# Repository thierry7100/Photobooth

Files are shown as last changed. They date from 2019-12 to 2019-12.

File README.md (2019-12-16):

## Software
* PhotoBooth_3Img_mariage.py : PhotoBooth main daemon. handle taking picture and upload to google drive
* listen-for-shutdown.py : management software :
  * starting/stopping camera_btn.py (short press)
  * powering off RPi (long press)
* *.service : systemctl services definition

## Install

Based on [Raspbian](https://www.raspberrypi.org/downloads/raspbian/)

Install shutdown service

    sudo cp listen-for-shutdown.service /etc/systemd/system/
    sudo systemctl daemon-reload
    sudo systemctl enable listen-for-shutdown.service
    sudo systemctl start listen-for-shutdown.service

Install Photobooth service

    sudo cp photobooth.service /etc/systemd/system/
    sudo systemctl daemon-reload
    sudo systemctl enable photobooth.service
    sudo systemctl start photobooth.service

Install needed python modules

    pip install --upgrade google-api-python-client

get api ID clients OAuth 2.0 client_id.json and put in current directory. See https://console.developers.google.com/apis/credentials

## Customization
There's some images displayed by the PhotoBooth service. They are overlayed on top of the live image.
The documentation explains how to change these images

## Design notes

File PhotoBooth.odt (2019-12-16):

Un photomaton (Photo-Booth) pour animer des événements

Ce type d’équipement permet de s’amuser lors d’événements comme des mariages, fêtes diverses… Il permet de réaliser des photos où les personnes « se lâchent » ou pas d’ailleurs !

J’ai réalisé ce type d’équipement pour le mariage de ma seconde fille. Lors du mariage de la première, elle avait loué ce type d’équipement, cela est revenu à 300€ pour le week-end ! Je me suis dit que je devais pouvoir faire sinon mieux, au moins différent et pour un budget beaucoup plus modique, tout en restant disponible pour d’autres occasions.

Les photos sont loin d’avoir la qualité d’un appareil numérique récent, mais cela reste tout à fait viable pour ce type d’usage.

J’ai choisi délibérément un style rétro, mais ne vous y fiez pas, cet appareil permet d’imprimer 3 photos regroupées en direct, et permet également d’envoyer en direct les photos prises sur Google Drive pour les partager ensuite facilement. Ceci nécessite bien sûr une connectivité réseau, Wifi ou Ethernet.

Le logiciel permet relativement facilement de configurer le nombre de photos à imprimer (cela peut être 0), le compte Google Drive à utiliser, l’image de fond choisie...

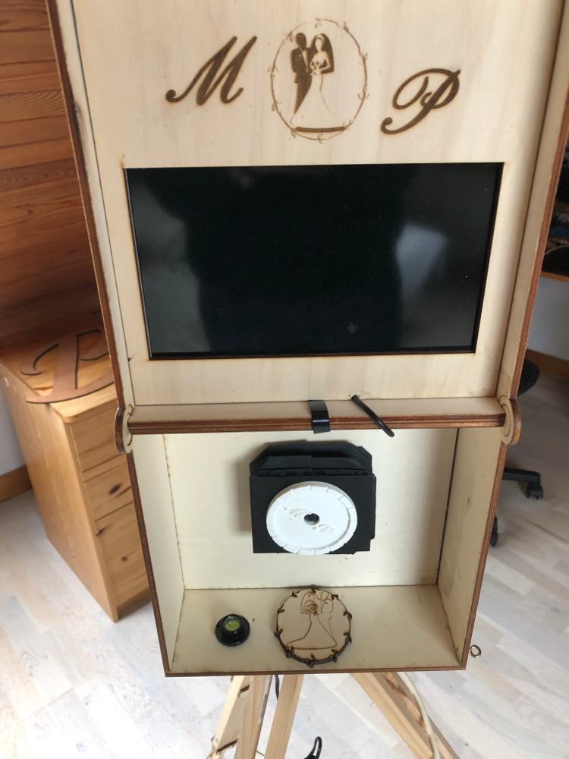
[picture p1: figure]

# Matériel

1. Du bois… J’ai utilisé du contreplaqué peuplier (très clair) pour le boîtier, du tasseau en pin pour les pieds, un peu de MDF pour le support d’objectif.
2. Un Raspberry PI3 et sa caméra v2.
3. Un petit niveau (acheté sur un site de camping car), non obligatoire, mais permet de mettre l’appareil à peu près à l’horizontale.
4. Du papier noir épais pour le soufflet (acheté à Bureau Vallée).
5. Un écran 9 pouces avec entrée HDMI, acheté chez Ali Express. La résolution est de 800 par 480 pixels. L’écran n’est pas de très bonne qualité, mais le prix (27€) est au rendez-vous. https://fr.aliexpress.com/item/32707130877.html?spm=a2g0s.9042311.0.0.27426c37Hc6uQq
6. Un câble HDMI réalisé en circuit imprimé souple pour relier l’écran et permettre de mettre l’écran dans le couvercle du boîtier. https://www.amazon.fr/dp/B01EWSKVDQ/ref=pe_3044141_185740131_TE_item
7. Une alimentation 5V USB, pour l’écran et le Raspberry. J’ai choisi e prendre deux alimentations différentes pour ne pas avoir de problème de consommation.
8. Un petit amplificateur BF avec un haut parleur pour la partie son. https://www.gotronic.fr/art-kit-2165b-653.htm.
9. Des boutons, issus d’un site de boutons de gamers… http://www.joystick-arcade.com/fr/
10. Quelques vis de tailles diverses...

# Boîtier

J’ai utilisé les boîtes générées par le site de Florian Festi pour cette occasion. Voir www.festi.info/boxes.py

Parmi toutes les formes de boîtes disponibles, j’ai utilisé une avec des charnières en bois intégrées qui permettent de replier l’écran une fois rangé. L’écran est ainsi au dessus de l’appareil, et permet une prise de vue correcte, avec un effet « faux jeton » à mon avis moins marqué que s’il était déporté sur le côté. Pour les meilleures prises de vue possibles, il faut néanmoins regarder l’objectif et pas l’écran !

La décoration est très ‘kitch’, j’en conviens mais si vous voulez en changer ne vous gênez pas !

Aujourd’hui, j’utiliserai plutôt le plugin inkscape que j’ai réalisé (on n’est jamais mieux servi que par soi-même pour se faire un peu de pub…), voir https://wiki.fablab-lannion.org/index.php?title=Generateur_de_boites. Je recommande ce plugin, car le dessin généré par le site de Florian Festi présente quelques défauts (mineurs) et surtout le fichier SVG généré incorpore de nombreux arrondis qui passent très mal avec RDWorks et notre découpeuse Laser. Les arrondis sont transformés encercles complets, et génèrent beaucoup de mouvements parasites pouvant conduire à des décalages.

## Support écran

Le support d’écran est coincé dans le couvercle du boîtier. Il est constitué de 3 plaques permettant de fixer l’écran. La première plaque (gravée) est réalisée en CP5mm est la plaque externe. LA seconde plaque (MDF 3mm) permet de caler l’écran, la troisième plaque (visée sur la seconde empêche l’écran de bouger). Prendre du bois de 3mm d’épaisseur, c’est celle de l’écran. La carte contrôleur d’écran est vissée sur la 3ème plaque. Cet assemblage est ensuite inséré dans le couvercle, la profondeur est dans mon cas réglée par des tasseaux collés dans le couvercle. J’ai collé l’ensemble, ce n’est pas démontable, mais cela ne me paraissait pas nécessaire.

Voir fichier BoiteEcran.XXX dans le répertoire Decoupe.

# Objectif photo

J’utilise la caméra du raspberry (v2) directement, mais il faut l’habiller.

## Le soufflet

Tout bon appareil rétro qui se respecte doit avoir son soufflet ! Ici bien sûr il ne sert à rien. J’ai réalisé le mien en papier épais, genre papier canson en plus épais (noir). Je me suis basé sur cet article : http://www.galerie-photo.com/construire-soufflet-chambre-photo.html

Lisez l’article, il vous explique la méthode (non triviale) utilisée pour plier le soufflet.

J’ai découpé le papier au laser, j’ai également utilisé la découpeuse laser en mode ‘gravure’ pour marquer les lignes de pliage du soufflet.

Voir fichiers Decoupe/Soufflet2.XXX

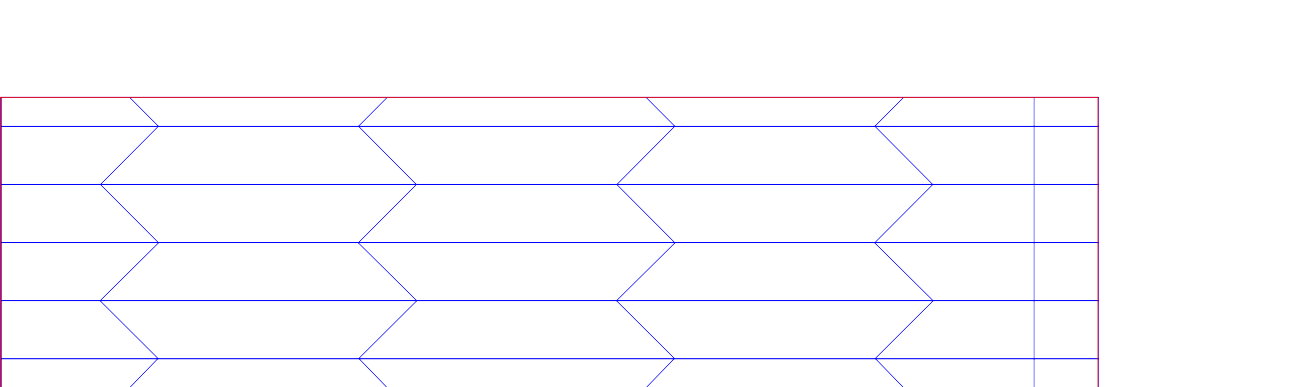
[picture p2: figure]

Ce soufflet vient habiller (cacher) le support d’objectif.

## Support d’objectif

C’est une petite ‘boite’ en MDF 3mm qui vient déporter vers l’avant l’objectif et qui est cachée par le soufflet.

Cette boite est encastrée sur une plaque en contreplaqué 5mm (dans mon cas).
Voir les fichiers Decoupe/SupportObjectif.XXX

Le dessin utilise plusieurs couleurs car deux matériaux sont utilisés (MDF et CP), d’où la nécessité de faire la découpe en 2 fois.

## Couvre Objectif camera Pi

Ce support réalisé en PLA (impression 3D) permet de faire tenir la caméra du Raspberry qui peut être vissé dessus. Voir fichiers dans le répertoire 3D.
J’ai utilisé OpenSCAD et le plugin Inkscape path2OpenSCAD pour réaliser la pièce. La version courante d’OpenSCAD (2019) devrait permettre de le réaliser directement (possibilité d’importer des SVG).

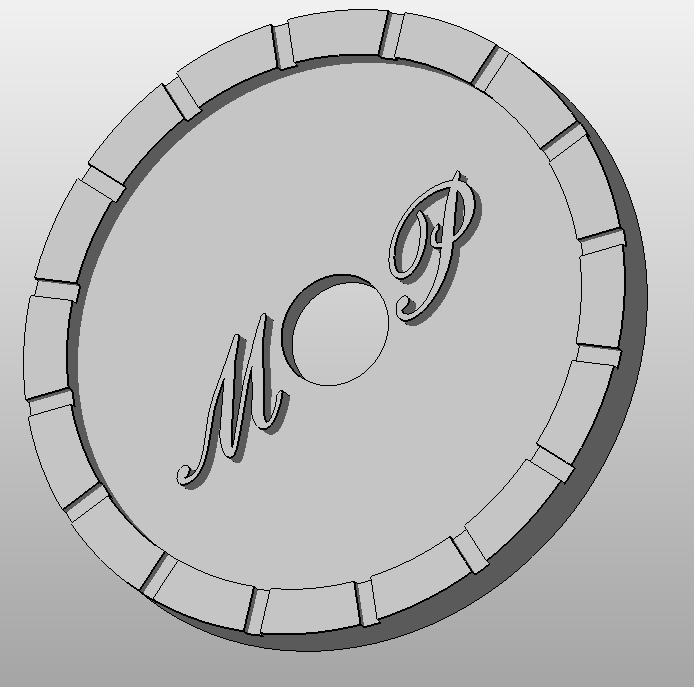
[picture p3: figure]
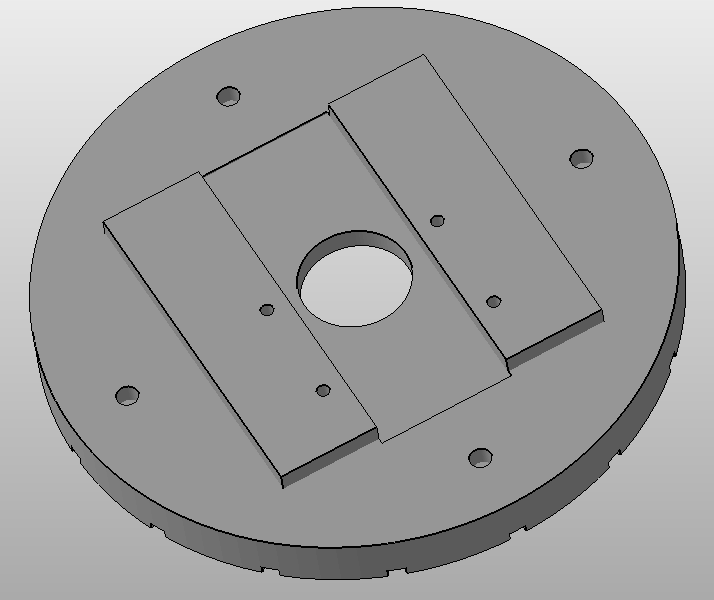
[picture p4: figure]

Les 4 petits trous permettent de fixer la caméra du Raspberry les 4 plus gros de fixer cette face avant au support d’objectif précédent.

Ce couvre objectif doit être fixé après le soufflet, il vient masquer les rebords du soufflet.

# Le pied

Le pied (trépied) est réalisé en bois, à partir de tasseaux en pin, et de pièces en CP5 découpées laser pour permettre de régler la hauteur du pied.

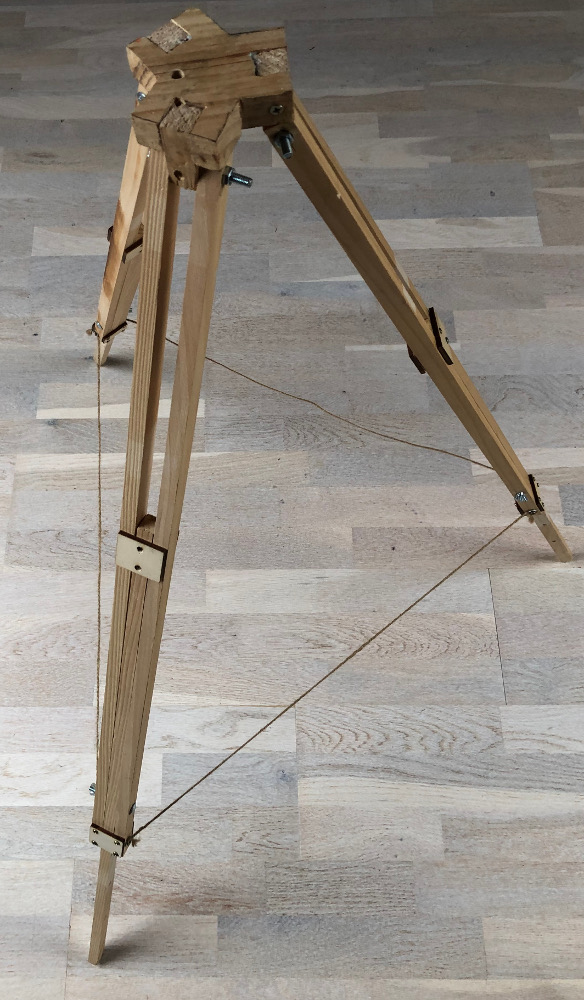
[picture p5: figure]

La ficelle évite au pied de trop s’écarter, pas très technologique, mais efficace ! Elle est coincée par les arrêts du bas du pied. Prendre des morceaux de même taille, a priori le triangle devrait être équilatéral.

La tête de pied est réalisée en bois, j’avais fait une première version imprimable en 3D, mais réalisée en ABS, elle s’est cassée immédiatement, les couches se sont décollées. Peut-être en nylon ? J’ai donc pris ma scie et mes deux mains gauches, le résultat n’est pas très joli, mais c’est caché sous le boîtier en fonctionnement. J’ai utilisé un morceau de tasseau en sapin épais de 30 mm je crois.

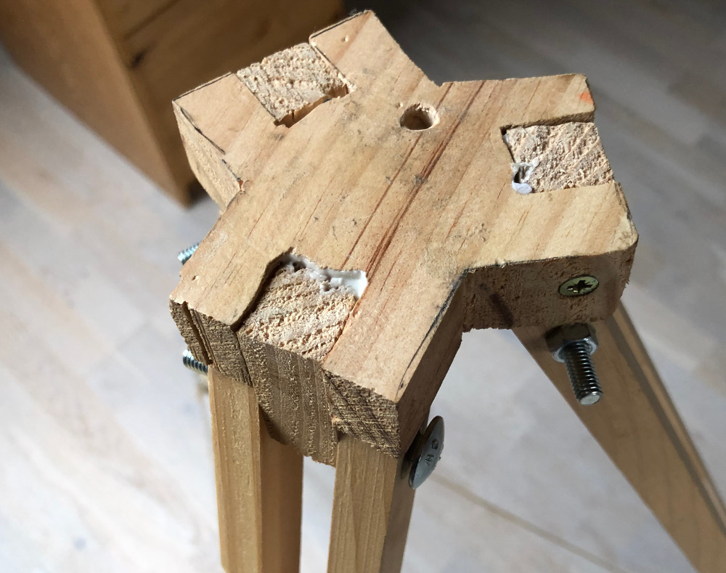
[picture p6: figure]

Le pied est réglable en hauteur, j’ai utilisé des petites cales découpées laser pour cela.

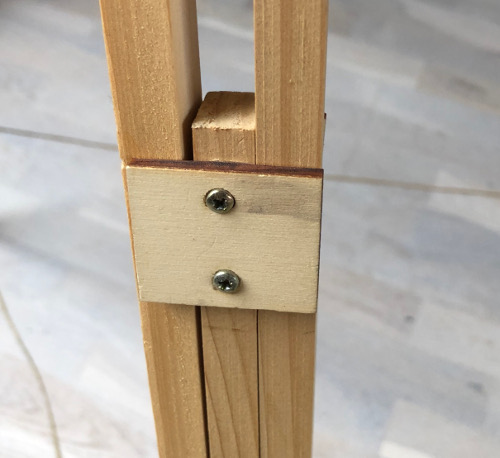
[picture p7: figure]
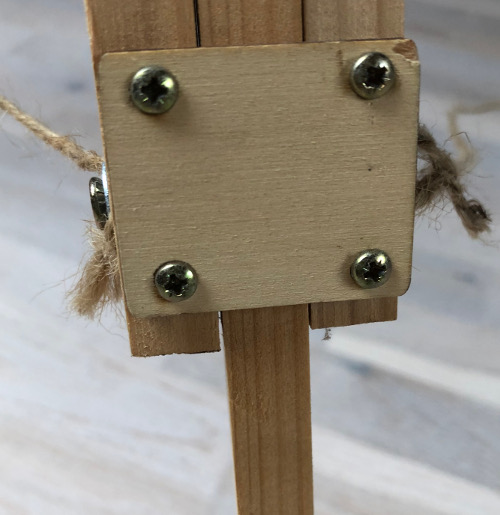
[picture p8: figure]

# Boite des boutons

Les boutons sont logés dans une boîte séparée, qui peut être approchée des personnes posant devant l’appareil. Le fil doit être assez long à cet effet.

J’ai encore une fois utilisé une boîte provenant du site de Florian Festi, réalisée en MDF avec des coins arrondis. Mon nouveau Plugin, permet également de réaliser ce type de boîte.

Rien de spécial ici, le volume est assez conséquent, mais on peut appuyer sans crainte avec le pied sur le bouton principal.

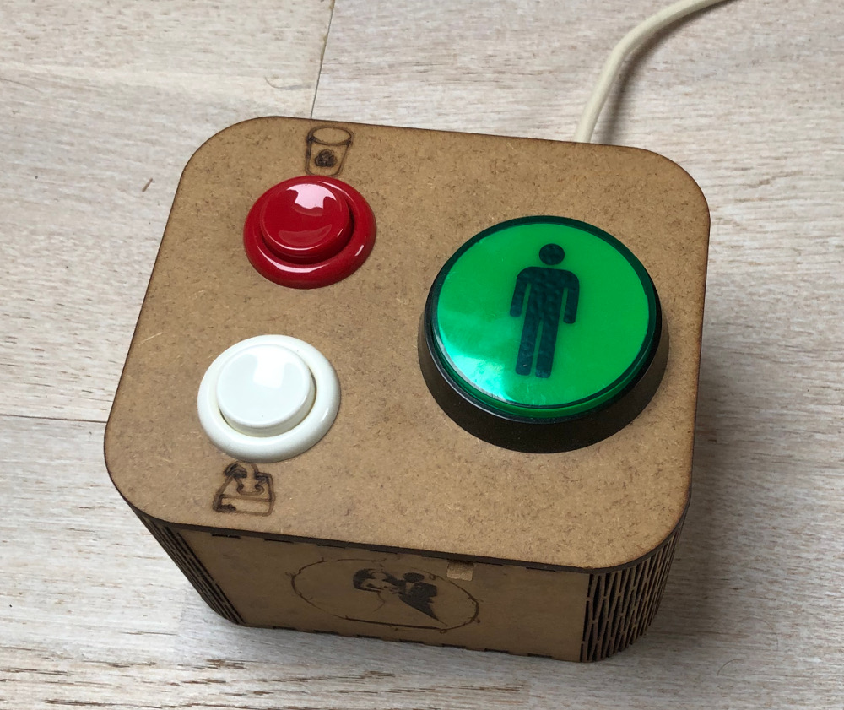
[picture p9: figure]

# Partie câblage

Il faut évidemment relier le Raspberry à la fois à la boîte des boutons et au divers éléments du boîtier.

Le schéma utilisé est le suivant

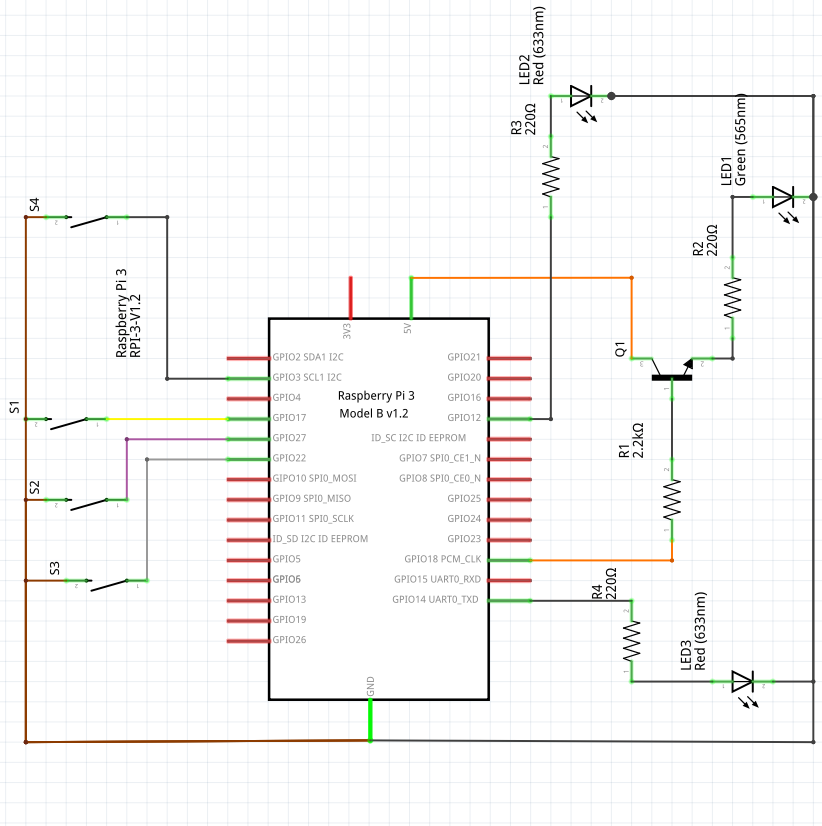
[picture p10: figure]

Le transistor Q1 est logé dans la boîte des boutons, pas vraiment sûr qu’il soit obligatoire, mais il ne gêne pas non plus ! Les boutons S1, S2, S3 sont dans la boîte des boutons, le bouton S4 permet d’arrêter le logiciel ou le Raspberry proprement. S1 est le gros bouton vert, S2 le rouge et S3 le blanc.

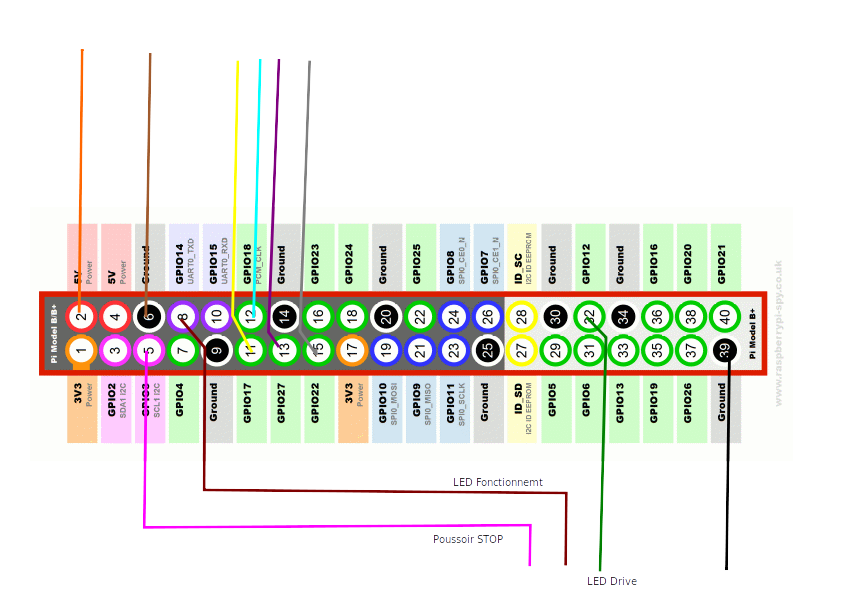
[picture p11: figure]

Pour relier la boîte des boutons, j’ai utilisé du fil de câblage téléphonique (4 paires), mais tout autre type de câble avec au moins 6 fils convient.

# Logiciel

Le logiciel est écrit en python, le source est libre.

Les logiciels sont installés en tant que services au niveau du pi, ils sont lancés au démarrage du système.

## Module Bouton

Le premier module très simple, sert à arrêter relancer le service photo lui-même. Si le bouton est appuyé pendant plus de 3s, le Raspberry s’éteint. Cette manipulation est obligatoire sous peine de gros problèmes au niveau de la carte SD qui supporte mal des arrêts brutaux, sans passer par un ‘shutdown’ propre.

## Module Photo

C’est le module principal. J’ai choisi de travailler en demi résolution au niveau de la caméra PI, cela suffit largement, de toute manière l’optique est très loin de la qualité voulue pour la pleine résolution (pas d’auto focus…). Et même avec un Raspberry PI3, les traitements d’image sont conséquents.

Les divers fichiers png : Accueil.png, SecondePhoto.png, DernierePhoto.png, ApresPhoto2.png sont utilisés en sur impression au dessus de l’image ‘live’ de la caméra pour donner des instructions. Ils doivent être de la résolution de l’écran (800x480) mais peuvent être modifiés sans problème.

Le fichier Fond.png est utilisé pour compenser la différence de taille entre la caméra (format 4/3) et l’écran (format 16/10 800x480). La photo elle même est affichée en 640x480 pour respecter le format. Un écran 4/3 serait plus adapté, mais je n’en ai pas trouvé dans ces dimensions…

A chaque photo, un message sonore (du style Souriez, Cheese) est joué de manière aléatoire parmi 7 messages différents. Cela peut être évidemment modifié, aussi bien au niveau des messages que du nombre. Attention toutefois à coder les messages en .WAV, le décodage MP3 prend un peu trop de temps CPU, et provoque des craquements pendant la lecture. La bibliothèque son utilisée est assez simple et supporte mal la charge CPU (affichage des images en parallèle).

L’appareil prend 3 photos successivement, puis regroupe ces 3 photos en une quatrième. Le fond de la quatrième photo est paramétrable suivant l’événement considéré. La quatrième photo est imprimée en N exemplaires et est disponible rapidement. J’ai choisi de faire 2 exemplaires pour le mariage de ma fille, une photo pour les personnes, la seconde destinée au livre d’or du mariage.

## Impression

Le logiciel est capable d’imprimer les photos réalisées, il faut pour cela avoir une imprimante (photo) connectée au Raspberry. La connexion peut être soit USB, soit Wifi.

Il vous faut tout d’abord choisir une imprimante qui possède un driver Linux, et où le source est disponible. Vous devrez en effet compiler le driver sur le Raspberry, les versions pour ARM n’étant généralement pas disponibles directement.

Une fois le driver disponible, vous pouvez installer l’imprimante via CUPS et faire des premiers test d’impression. Pensez à fixer le type de papier par défaut et sa taille via CUPS.

Il doit être également possible d’ajouter des drivers via Gutenprint (plus de choix de type d’imprimante) mais je ne l’ai pas testé, mon imprimante avait un driver disponible et n’était pas disponible via Gutenprint ! Mais je sais qu’il est possible de connecter des imprimantes photo Canon Selphy via Gutenprint.

## Création des autorisations via Google drive API

Ceci est à faire, à chaque fois que vous souhaitez changer de répertoire Google Drive. Cela peut être réalisé, soit sur le PI soit sur votre PC, il faut alors télécharger les fichiers sur le PI...

1. Se connecter sur son compte Google via le navigateur
2. Aller sur https://developers.google.com/drive/api/v3/quickstart/python
3. Cliquer sur Enable Drive API, cela génère un fichier credentials.json qui va être ensuite utilisé pour accéder au service.
4. Si vous faites cela depuis votre PC, téléchargez le fichier ainsi obtenu dans le répertoire principal. Ce fichier doit être stocké dans le photo booth et référencé dans le fichier photoBooth.cfg par l’entrée SecretFile. Personnellement j’ai utilisé mon PC pour réaliser ces opérations, l’écran du PI (800x480) est vraiment tout petit...
5. Dans la même page, le logiciel python QuickStart.py permet de générer la clef. Vous pouvez donc le faire « OffLine » et transférer ce fichier ensuite sur le PI (dans le répertoire ~/.credentials). Mais cette génération est également intégrée au logiciel PhotoBooth. Il faut néanmoins que le navigateur soit ouvert pour créer ce fichier (le navigateur ne se lance pas directement). Bien sûr ceci n’est nécessaire que la première fois, ensuite si le fichier est présent il sera utilisé. Identifiez vous avec votre compte Google et le fichier d’accès est créé, avec PhotoBooth il est directement stocké dans le répertoire ~/.credentials où il sera utilisé. Référencez le fichier créé dans le fichier photoBooth.cfg par l’entrée CredentialFile. Si vous créez ce fichier sur le Raspberry, il est possible que certaines des toutes premières photos ne soient pas envoyées vers le Google Drive, le temps que la procédure soit terminée.

## Fichier de configuration

Les principaux paramètres de fonctionnement sont configurables via le fichier PhotoBooth.cfg

Exemple de fichier de configuration

[Printer]

PrinterName=YOUR_PRINTER

NbCopies=2

[Picture4]

PictureName=/home/pi/photobooth/YourBackGroundPicture.png

[Upload]

GoogleDrive=1

SecretFile=/home/pi/photobooth/YourSecretFile.json

CredentialFile=YourCredentialFile

[Directories]

WorkingDir=/home/pi/photobooth

PhotoDir=/home/pi/YourDirectory

La première section est dédiée à l’imprimante. Le nom est celui de l’imprimante pour votre système quand vous l’avez installée via CUPS. La seconde ligne indique le nombre de copies à imprimer, 0 si vous ne souhaitez pas d’impression.

La section Picture4 donne le chemin de l’image utilisée comme fond d’écran. Cette image doit avoir une résolution de 4096x2730 pixels pour que l’impression soit bien cadrée dans du papier 10x15 (4x6 pouces).

La section Upload fixe les paramètres utilisés pour l’Upload via google drive. Quand le premier est à 0, pas d’upload prévu. Pensez à la fixer à 0, si vous n’avez pas de connectivité réseau sinon, le logiciel va lancer de nombreux threads pour tenter l’upload, qui ne vont jamais aboutir et vont finir par surcharger le processeur.

La dernière section donne le répertoire ou seront stockées les photos.

# Amélioration possibles

Il y en a certainement beaucoup, à vous de jouer et bien sûr de republier votre travail (licence GPL).

# Crédits

Un grand grand merci à Jérôme pour sa version dont je me suis très largement inspiré.

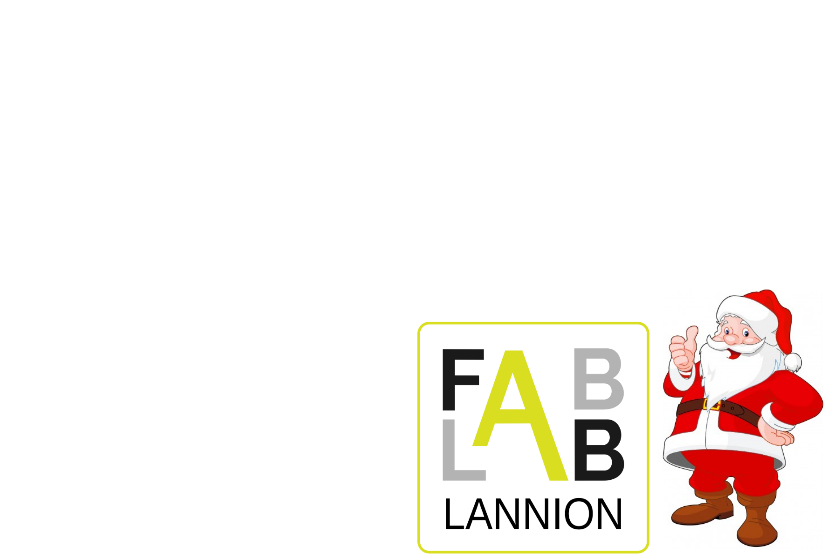
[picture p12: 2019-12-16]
FondNoel.png

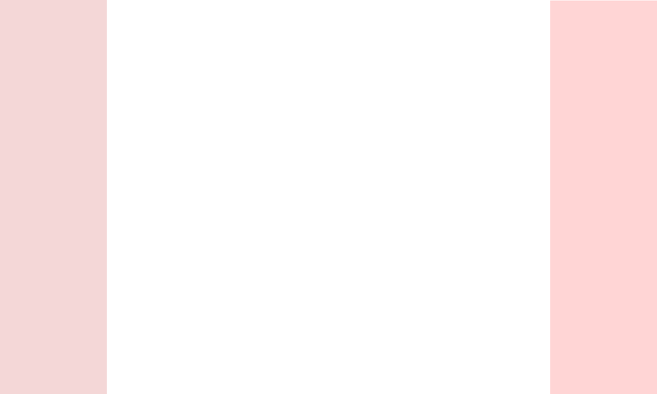
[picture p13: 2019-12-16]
Fond.png

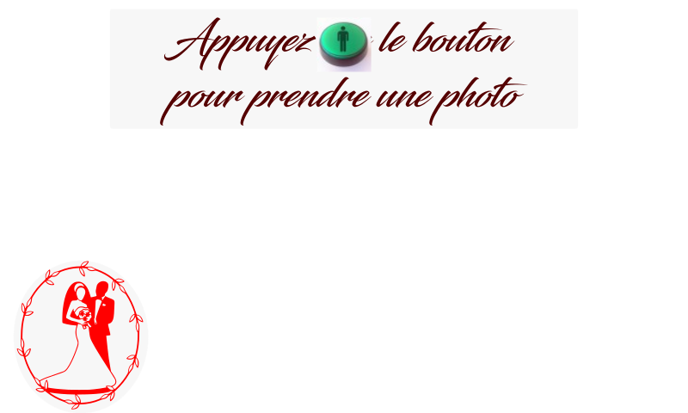
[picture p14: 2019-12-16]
Accueil.png

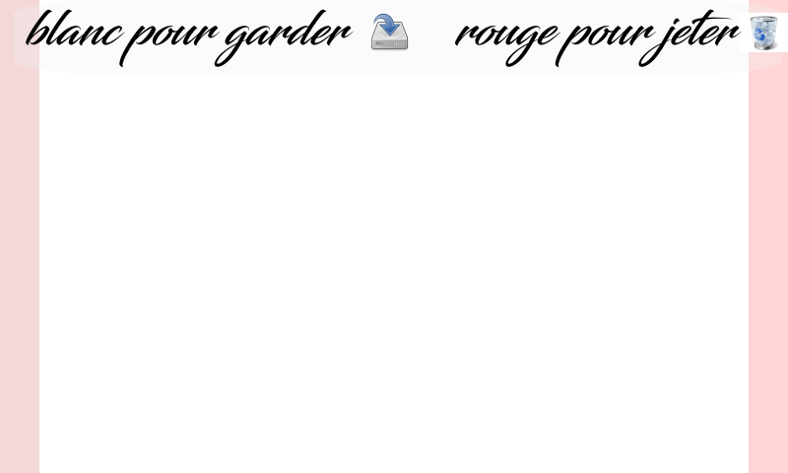
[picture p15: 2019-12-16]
ApresPhoto2.png

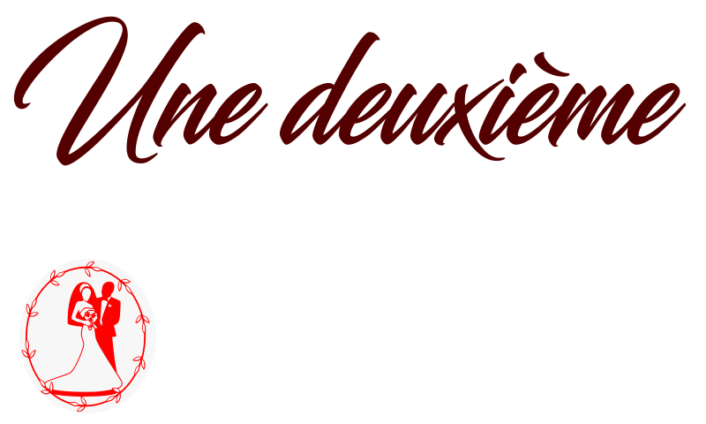
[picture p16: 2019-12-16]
SecondePhoto.png

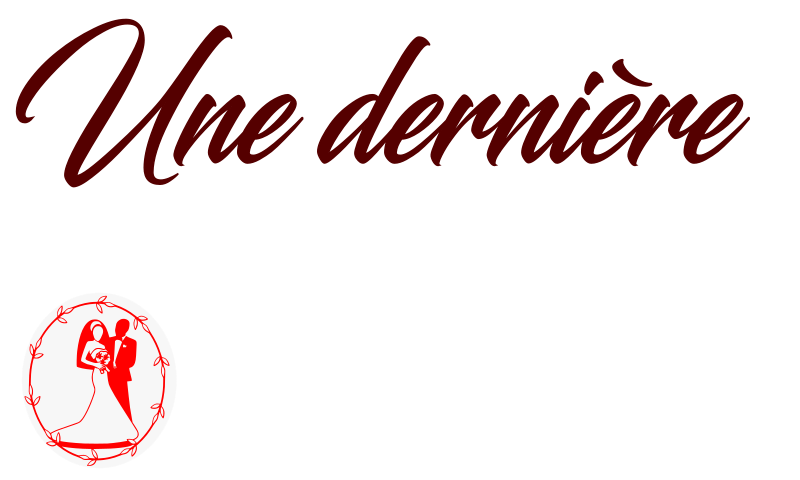
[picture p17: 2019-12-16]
DernierePhoto.png

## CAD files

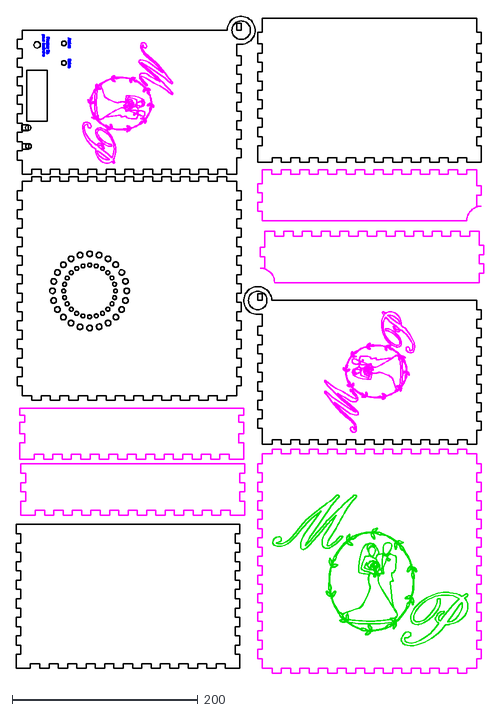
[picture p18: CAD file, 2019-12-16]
BoiteComplete_final.dxf
504.1 x 707.9

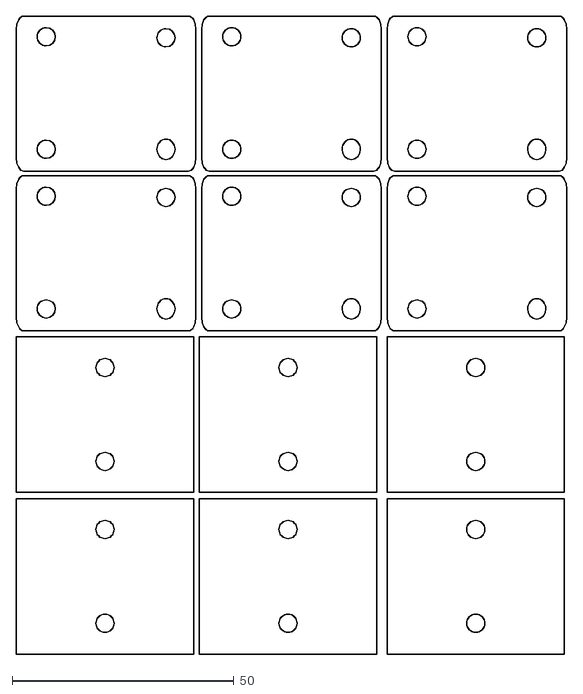
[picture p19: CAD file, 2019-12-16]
Pied.dxf
124.1 x 143.9

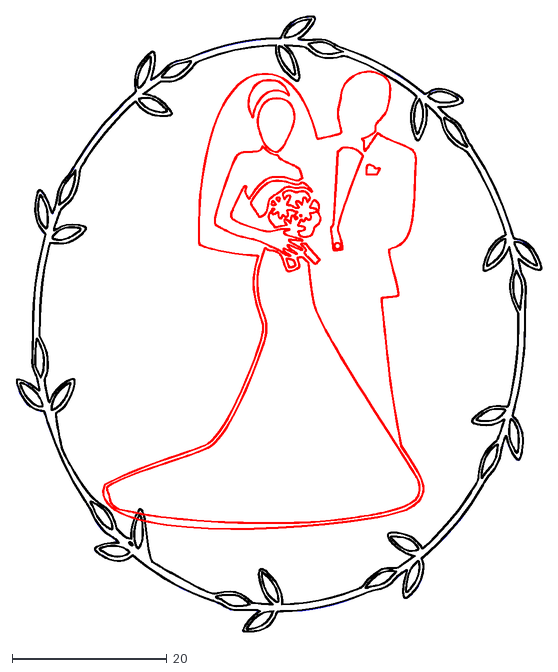
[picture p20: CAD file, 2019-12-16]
Logo_Tour.dxf
67.9 x 79.6

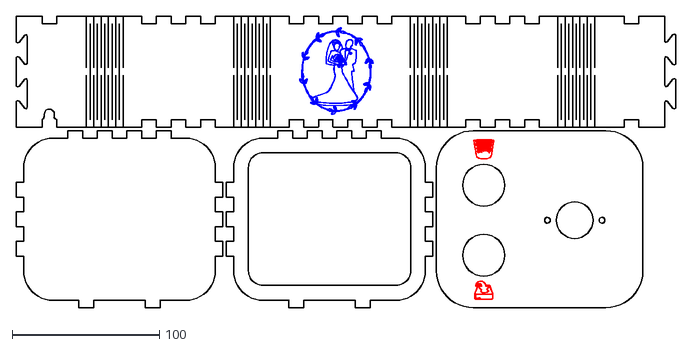
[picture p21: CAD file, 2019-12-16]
BoiteBoutons.dxf
448.0 x 197.9

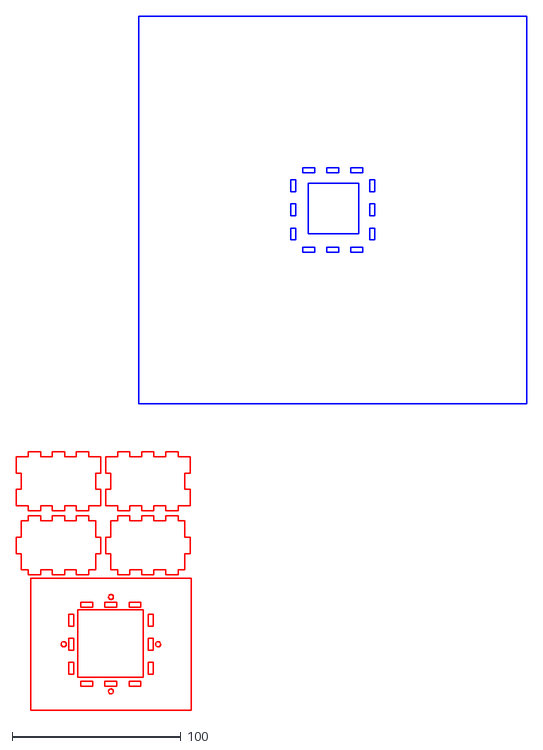
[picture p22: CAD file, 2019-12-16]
SupportObjectif.dxf
302.6 x 411.5

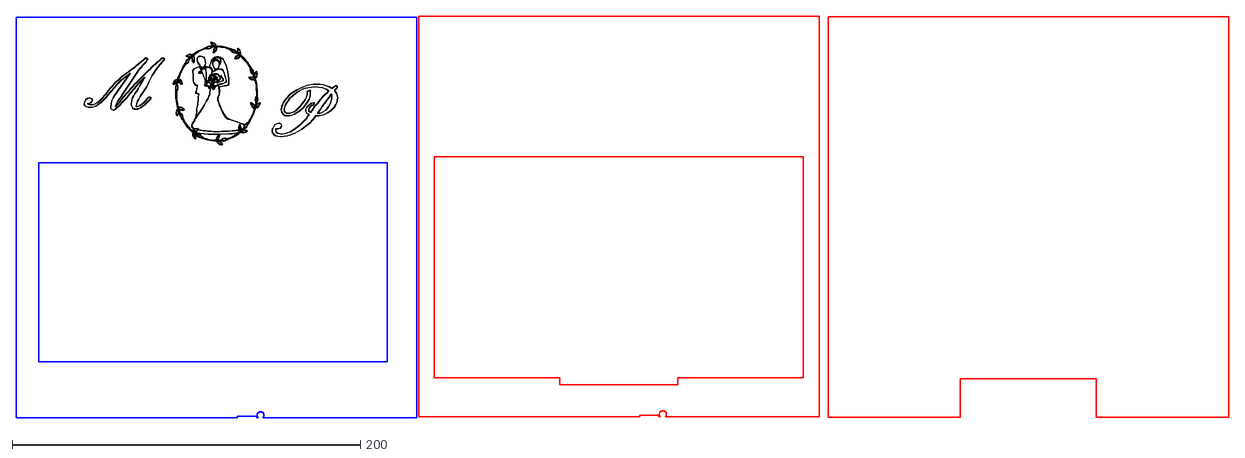
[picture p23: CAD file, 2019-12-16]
BoiteEcran.dxf
696.2 x 230.5

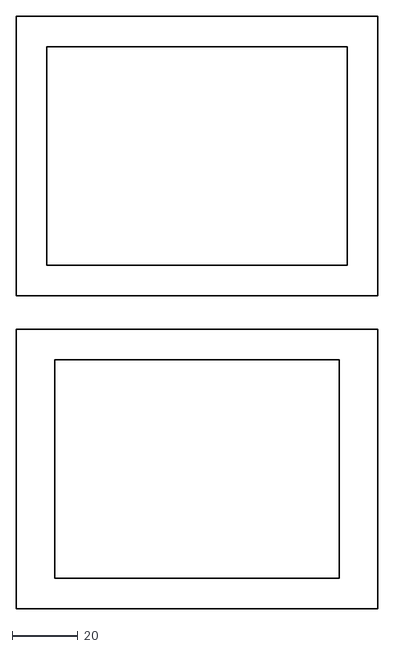
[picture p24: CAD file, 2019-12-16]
SupportCarte.dxf
110.0 x 180.3

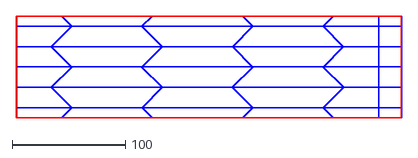
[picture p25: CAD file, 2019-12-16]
Soufflet2.dxf
340.2 x 90.0

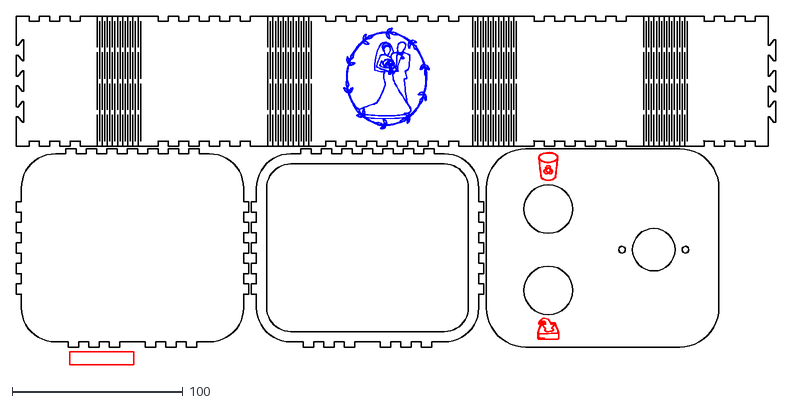
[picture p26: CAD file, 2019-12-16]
Boutons2.dxf
444.6 x 204.2

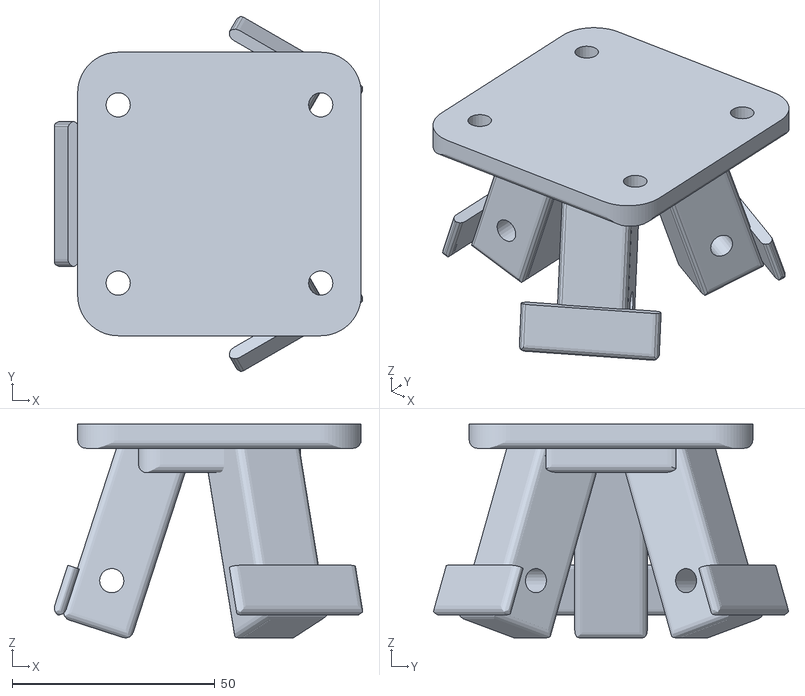
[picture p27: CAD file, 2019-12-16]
Trepied_v2.stl
76.1 x 87.6 x 52.8

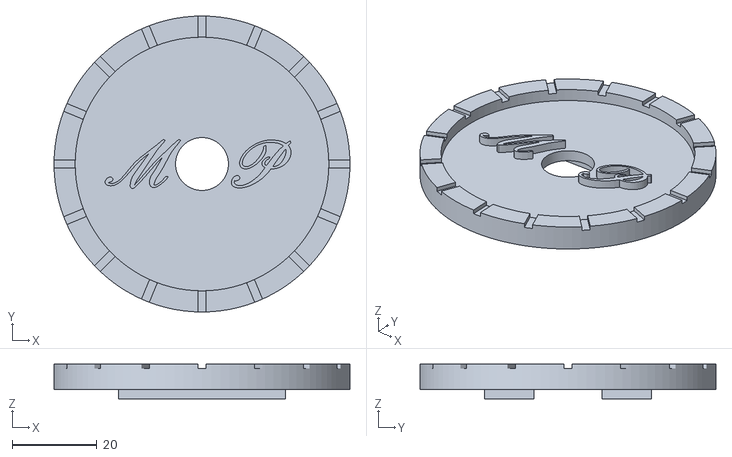
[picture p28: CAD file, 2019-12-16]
objectif_th.stl
70.0 x 70.0 x 8.25

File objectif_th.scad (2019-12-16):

$fn=100;

fudge = 0.1;

module poly_path1578(h)
{
  scale([25.4/90, -25.4/90, 1]) union()
  {
    linear_extrude(height=h)
      polygon([[-28.933340,15.386670],[-28.400000,15.386670],[-27.267500,15.212503],[-26.180000,14.713336],[-25.362500,13.924169],[-25.125313,13.431772],[-25.040000,12.880000],[-25.208333,12.062499],[-25.666668,11.459999],[-26.345003,11.087500],[-27.173340,10.960000],[-28.052611,11.062604],[-28.877506,11.350833],[-29.628650,11.795311],[-30.286670,12.366665],[-31.245834,13.772497],[-31.508229,14.548226],[-31.600000,15.333330],[-31.513336,16.013331],[-31.226670,16.613330],[-30.475005,17.389166],[-29.493339,17.900001],[-28.271670,18.180836],[-26.800000,18.266670],[-25.040000,18.160000],[-23.765521,17.812707],[-22.574168,17.341665],[-20.393336,16.093331],[-18.402504,14.545000],[-16.506670,12.826670],[-14.033338,10.213334],[-10.800000,6.480000],[-5.306670,0.133330],[-2.185001,-2.859169],[1.146666,-5.646669],[4.880000,-8.506670],[-7.546670,8.720000],[-8.719169,10.749169],[-9.686669,13.033336],[-10.344170,15.507503],[-10.586670,18.106670],[-10.458337,19.135000],[-10.080005,19.893334],[-9.461673,20.371668],[-8.613340,20.560000],[-7.760000,20.400000],[-6.114481,19.166876],[-3.805837,16.915002],[1.913329,10.600002],[11.546660,-0.560000],[15.546660,-4.613330],[16.240000,-5.253330],[14.266660,-1.840000],[10.939995,3.879999],[8.453330,7.760000],[7.314164,9.370831],[6.419996,11.086664],[5.835828,13.032497],[5.626660,15.333330],[5.689993,16.475834],[5.893327,17.433335],[6.256663,18.220834],[6.800000,18.853330],[7.819996,19.546665],[9.200000,19.760000],[10.259996,19.659999],[11.440000,19.280000],[12.852497,18.541665],[14.459996,17.493331],[17.840000,14.746670],[20.006665,12.440000],[20.787497,11.431666],[21.093330,10.853330],[20.773330,10.426670],[19.920000,10.426670],[18.960000,10.520003],[18.480000,11.173330],[16.999998,13.000000],[15.440000,14.586670],[13.818332,15.941667],[12.346664,16.946667],[11.074996,17.571669],[10.053330,17.786670],[9.493330,17.646669],[9.413330,16.986670],[9.713331,15.629166],[10.413331,13.886665],[11.453330,11.894166],[12.773330,9.786670],[16.126664,4.613335],[19.440000,-1.520000],[22.239999,-6.786665],[24.400000,-10.373330],[26.470000,-13.142500],[28.840000,-16.086667],[31.600000,-19.600000],[31.493331,-19.989169],[31.026664,-20.273336],[30.053330,-20.506670],[25.339998,-16.453334],[22.080829,-13.486666],[20.346660,-11.760000],[19.793330,-11.106668],[18.640000,-10.053330],[12.133330,-3.920000],[9.286666,-0.933332],[6.000000,2.853330],[-4.880000,15.440000],[-6.960000,17.626670],[-5.733340,14.960000],[-4.040004,12.080000],[-1.466670,8.240000],[11.973330,-11.653330],[18.213330,-18.960000],[18.613330,-19.560000],[18.533330,-19.920000],[17.200000,-20.560000],[15.333330,-19.066670],[11.613331,-15.946667],[5.893330,-11.546670],[-1.860002,-5.553335],[-4.344170,-3.424167],[-6.533340,-1.360000],[-8.966671,1.293334],[-12.400000,5.466670],[-15.620001,9.380001],[-17.680000,11.653330],[-19.535000,13.419166],[-21.280001,14.740001],[-22.945001,15.650836],[-24.560000,16.186670],[-26.106670,16.293330],[-27.820001,16.080000],[-28.454170,15.798336],[-28.933340,15.386670]]);
  }
}


module poly_path1552(h)
{
  scale([25.4/90, -25.4/90, 1]) union()
  {
    difference()
    {
       linear_extrude(height=h)
         polygon([[7.333332,-5.680020],[7.199999,-5.920019],[6.746672,-6.000020],[5.721984,-5.863561],[4.709171,-5.488352],[3.740107,-4.925643],[2.846669,-4.226684],[1.414169,-2.625016],[0.938857,-1.824808],[0.666672,-1.093350],[0.586669,-0.273347],[0.666672,0.506650],[0.998335,1.244982],[1.560002,1.933315],[3.173332,3.119980],[2.213332,4.399980],[-0.373335,7.733315],[-3.119998,10.586650],[-5.049478,12.272588],[-6.985832,13.764151],[-8.910937,15.051964],[-10.806666,16.126651],[-12.654895,16.978838],[-14.437498,17.599150],[-16.136351,17.978213],[-17.733328,18.106650],[-19.481662,17.949983],[-20.999996,17.453316],[-21.613539,17.064983],[-22.098331,16.576649],[-22.430623,15.983314],[-22.586664,15.279980],[-22.426664,13.999980],[-21.413331,14.106650],[-20.165831,13.932483],[-19.033330,13.433316],[-18.210829,12.644149],[-17.976766,12.151752],[-17.893328,11.599980],[-18.061662,10.849983],[-18.519996,10.239983],[-19.198331,9.829981],[-20.026668,9.679980],[-20.937292,9.778001],[-21.751666,10.054147],[-22.473540,10.481544],[-23.106665,11.033315],[-24.121664,12.402483],[-24.826664,13.946650],[-25.093331,15.653320],[-24.933331,16.773320],[-24.592185,17.512591],[-24.094165,18.167486],[-23.447394,18.733630],[-22.659998,19.206650],[-20.695833,19.855814],[-18.266668,20.079980],[-15.707918,19.901543],[-13.056667,19.382480],[-10.350417,18.547168],[-7.626667,17.419981],[-4.922918,16.025294],[-2.276668,14.387481],[0.274582,12.530918],[2.693331,10.479980],[5.233334,7.919981],[7.493332,5.039980],[8.186672,4.133320],[9.200002,4.133320],[10.906672,4.026650],[12.609274,3.731859],[14.297502,3.258318],[15.941981,2.622276],[17.513334,1.839984],[18.982188,0.927692],[20.319167,-0.098350],[21.494896,-1.221890],[22.480002,-2.426680],[23.608336,-4.303349],[24.426668,-6.160017],[24.924999,-7.976685],[25.093332,-9.733350],[24.924998,-11.387516],[24.466665,-12.886684],[23.788333,-14.195852],[22.960002,-15.280020],[22.800002,-15.600020],[24.453332,-17.306680],[24.740003,-17.546684],[24.826672,-17.786680],[24.593335,-18.686680],[24.354167,-19.069180],[24.080002,-19.226680],[22.713335,-18.440016],[20.826672,-17.093350],[20.453332,-17.306680],[18.637502,-18.286680],[16.486669,-19.066681],[14.025835,-19.646681],[11.280002,-20.026680],[7.546672,-20.079980],[6.373332,-20.079980],[4.333854,-19.813522],[2.267502,-19.378313],[0.192398,-18.780604],[-1.873331,-18.026645],[-3.911560,-17.122686],[-5.904165,-16.074977],[-7.833019,-14.889768],[-9.679998,-13.573310],[-12.466665,-11.213311],[-14.693328,-8.773310],[-16.486667,-5.926646],[-17.679998,-3.119980],[-17.986663,-1.839976],[-18.053328,-0.559980],[-17.962391,0.545125],[-17.695829,1.500856],[-17.263017,2.307836],[-16.673330,2.966691],[-15.936142,3.478046],[-15.060830,3.842526],[-14.056767,4.060756],[-12.933328,4.133360],[-11.653328,4.026690],[-9.935830,3.547316],[-8.133331,2.771691],[-6.290831,1.733566],[-4.453331,0.466690],[-2.665830,-0.995186],[-0.973329,-2.618311],[0.579171,-4.368936],[1.946672,-6.213310],[3.333335,-8.759978],[3.776668,-10.038310],[4.080002,-11.386640],[4.186672,-13.199980],[4.186672,-14.106640],[4.106684,-15.119978],[3.961686,-15.396644],[3.706672,-15.493310],[2.053332,-14.799980],[1.960004,-14.573323],[1.946672,-13.786640],[1.833349,-12.639975],[1.520002,-11.493310],[0.925834,-9.969145],[0.086667,-8.339978],[-1.022501,-6.580809],[-2.426668,-4.666640],[-4.739998,-1.993310],[-7.173328,0.080020],[-9.266665,1.346687],[-11.279998,2.053360],[-12.506668,2.160020],[-13.962498,1.956687],[-15.033331,1.373354],[-15.694165,0.450021],[-15.919998,-0.773310],[-15.653328,-2.373310],[-15.079163,-4.005809],[-14.139998,-5.833310],[-12.930834,-7.690811],[-11.546668,-9.413310],[-9.529166,-11.454145],[-7.206666,-13.299978],[-4.654168,-14.895809],[-1.946668,-16.186640],[0.413332,-17.057477],[2.733334,-17.673313],[5.073334,-18.039147],[7.493332,-18.159980],[10.800002,-17.979147],[13.826670,-17.433313],[16.433337,-16.517477],[17.535419,-15.919246],[18.480002,-15.226640],[17.893332,-14.639980],[15.806669,-12.659978],[13.680002,-10.479980],[9.753337,-5.786641],[5.466672,-0.133310],[4.400002,1.306690],[3.493332,0.773360],[3.060003,0.166690],[2.906672,-0.559980],[3.013332,-1.199980],[3.866672,-2.639980],[4.853333,-3.653313],[5.840002,-4.026640],[6.320002,-4.133310],[6.886667,-4.806644],[7.333332,-5.679980]]);
       translate([0, 0, -fudge])
         linear_extrude(height=h+2*fudge)
           polygon([[20.560002,-12.240020],[20.773332,-10.106680],[20.654179,-8.950850],[20.380013,-7.780016],[19.386672,-5.253350],[17.817502,-2.647515],[16.884481,-1.412410],[15.833334,-0.286681],[14.649688,0.681547],[13.319167,1.444150],[11.827396,1.953003],[10.160002,2.159980],[9.626672,2.159980],[15.120002,-5.626680],[20.400002,-12.613350],[20.560002,-12.240020]]);
    }
  }
}
module facade() {

    difference() {
        union(){
        cylinder (d=70, h=3); // facade
        translate([0, 0, -1]) cube([39.5,39.5, 2.5], center=true);
        }
        translate([0, 0, -1]) cube([41,16, 2.6], center=true);
       translate ([0, 0, -20]) cylinder (d=12.5, h=100); // trou objectif
        // trous fixation
        translate ([-12.5, -10.5, -3]) cylinder (d=1.5, h=5);
        translate ([-12.5, 10.5, -3]) cylinder (d=1.5, h=5);
        translate ([0, -10.5, -3]) cylinder (d=1.5, h=5);
        translate ([0, 10.5, -3]) cylinder (d=1.5, h=5);
        fixations();
    };
}

// indentations bague
module bague_ident() {
	for (i = [0:22.5:360] ) {
		rotate (a = [0,0,i]) translate([-1, 27, 5]) cube ([2, 12, 2]);
	}
}

module bague() {
	difference() {
		translate ([0, 0, 3]) cylinder (d=70, h=3); // facade
		translate ([0, 0, 2]) cylinder (d=60, h=5); // facade
		bague_ident();
	}

}
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

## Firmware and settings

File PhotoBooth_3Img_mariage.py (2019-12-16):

#!/usr/bin/python3

from __future__ import print_function
import httplib2
import os, sys
import subprocess

from picamera import PiCamera
from time import *
from gpiozero import Button, LED, PWMLED
from PIL import Image

from apiclient import discovery
from oauth2client import client
from oauth2client import tools
from oauth2client.file import Storage
from apiclient.http import MediaFileUpload
from apiclient.discovery import build
from threading import Thread
import pygame
from pygame.locals import *
import random
import configparser

# If modifying these scopes, delete your previously saved credentials
# at ~/.credentials/drive_photobooth.json
SCOPES = 'https://www.googleapis.com/auth/drive.file'

APPLICATION_NAME = 'PhotoMariage'

#   Broches utilisées au niveau GPiO
#   Bouton pour lancer le cycle photo 
buttonPhoto = Button(17)
ledPhoto = PWMLED(18)       #   et la led incorporée au bouton
#   Bouton pour garder les photos prises
buttonKeep = Button(22)
#   Bouton pour jeter les photos prises
buttonThrow = Button(27)
#   Led utilisée pour indiquer qu'un transfert vers Google Drive est en cours
ledDrive = LED(12)

#   Variables globales
camera = PiCamera()
ButtonThrowIsPressed = 0
ButtonKeepIsPressed = 0

#   Les divers fichiers utilisés pour les effets sonores
SoundFiles = ['on fait cheese Cath.wav', 'ouistiti Isa.wav', 'et on sourit Cath.wav', 'cheese Isa.wav', 'Cheese Isa Cath.wav', 'Ouistiti Isa Cath.wav', 'Allez souriez Isa.wav']
NbSoundFiles = 7        #   Nombre de fichiers présents
random.seed()           #   Initialise le générateur aléatoire

#   Taille de l'écran
#   Utilise un écran 800x480 bon marché
Screen_Size_X   = 800
Screen_Size_Y = 480

#   Taille utilisée pour le Preview de la camera
#   Doit être au format 4/3 pour respecter les dimensions
#   Utilise la zone maximale de l'écran en respectant le format
Screen_Size_Preview_X  = 640
Screen_Size_Preview_Y  = 480

#   Nombre de transferts en cours vers Google Drive
NbUpload = 0

#   Résolution caméra Raspberry. 
#   Utilise la demi résolution, les images sont de qualité suffisante, et beaucoup moins lourd en charge CPU
Camera_X_Resolution = 1640
Camera_Y_Resolution = 1232

#   Les photos sont regroupées par 4 pour impression.
#   Positionne les 4 images dans l'image finale de manière centrée
#   L'impression utilise du papier 10x15, crée une image avec le même rapport (1.5)

QuadPhoto_Size_Y = 2730
QuadPhoto_Size_X = 4096

#Première image en haut à gauche
QuadPhoto_Img0_X  = 240
QuadPhoto_Img0_Y  = 104

#Seconde image en haut à droite
QuadPhoto_Img1_X  = 2210
QuadPhoto_Img1_Y  = QuadPhoto_Img0_Y                                           #   Centre l'image dans le quart en haut à droite

QuadPhoto_Img2_X = QuadPhoto_Img0_X
QuadPhoto_Img2_Y = 1466


camera.resolution = (Camera_X_Resolution, Camera_Y_Resolution)  #Travaille a demi resolution, suffisant pour l'application choisie et le regroupement des photos en 10x15

camera.annotate_text_size = 160
camera.hflip = False # horizontal flip to see as in a mirror
# this is not Needed, just add display_rotate=2 or lcd_rotate=2 in /boot/config.txt
camera.vflip = False # vertical flip if screen is upside down

config_file = '/home/pi/photobooth/photoBooth.cfg'
config = configparser.ConfigParser()
config.read(config_file)

#These fields are read from config file
PrinterName = config['Printer']['PrinterName']
NbPrintCopy = int(config['Printer']['NbCopies'])
ImageFond = config['Picture4']['PictureName']
ClientSecretFile = config['Upload']['SecretFile']
CredentialFileName=config['Upload']['CredentialFile']
WorkingDir = config['Directories']['WorkingDir']
PhotoDir = config['Directories']['PhotoDir']
UploadGoogleDrive = int(config['Upload']['GoogleDrive'])


def get_credentials():
    """Gets valid user credentials from storage.

    If nothing has been stored, or if the stored credentials are invalid,
    the OAuth2 flow is completed to obtain the new credentials.

    Returns:
        Credentials, the obtained credential.
    """
    #print("Looking for credentials")
    home_dir = os.path.expanduser('~')
    credential_dir = os.path.join(home_dir, '.credentials')
    if not os.path.exists(credential_dir):
        os.makedirs(credential_dir)
    credential_path = os.path.join(credential_dir, CredentialFileName)
    print ("get_credentials path :", credential_path)
    store = Storage(credential_path)
    #print("get_credentials #1")
    credentials = store.get()
    #print("get_credentials #2")
    if not credentials or credentials.invalid:
        print("get_credentials : no credentials yet...")
        flow = client.flow_from_clientsecrets(ClientSecretFile, SCOPES)
        flow.user_agent = APPLICATION_NAME
        credentials = tools.run_flow(flow, store)
        print('Storing credentials to ' + credential_path)
    #else:
    #   print("get_credentials OK")
    return credentials

def uploadToDrive (fname):
    """   Envoie un fichier vers Google Drive
    
    Ne retourne rien
    """
    if UploadGoogleDrive == 0:
        return
    credentials = get_credentials()
    http = credentials.authorize(httplib2.Http())
    service = discovery.build('drive', 'v3', http=http)

    folder_id = None;
    results = service.files().list(pageSize=10,fields="nextPageToken, files(id, name)").execute()
    items = results.get('files', [])
    if not items:
        print('No files found.')
    else:
        print('Files:')
        for item in items:
            #print('{0} ({1})'.format(item['name'], item['id']))
            if item['name'] == "PhotoMariage":
                folder_id = item['id']
    if not folder_id:
        # create dir
        file_metadata = {
            'name': 'PhotoMariage',
            'mimeType': 'application/vnd.google-apps.folder'
        }
        file = service.files().create(body=file_metadata, fields='id').execute()
        print ('Created Folder ID: %s' % file.get('id'))
        folder_id = file.get('id')
    # upload file
    file_metadata = {'name': os.path.basename(fname), 'parents': [folder_id] }
    print("begin uploading ", fname)
    media = MediaFileUpload(fname, mimetype='image/jpeg', resumable=True)
    #print("end Upload") 
    file = service.files().create(body=file_metadata, media_body=media, fields='id').execute()
    print ("Created File : %s (%s)" % (file.get('name'), file.get('id')))

def getImgScreenResolution (fname):
    """ Charge une image dans un buffer compatible avec la caméra Raspberry pour surimpression
        Le buffer fait Screen_Size_X x Screen_Size_Y, identique à la taille de l'écran
        L'image source doit être en mode RGBA (PNG par exemple) avec une taille égale à celle de l'écran
        Colle l'image initiale en haut à gauche de la zone
        
        Retourne l'image crée
    """
    # Charge l'image qui est de la taille écran
    img = Image.open(fname)
    print("Image : ", fname, " Size ", img.size[0], "x", img.size[1])
    if img.size[0] % 32 != 0 or img.size[1] % 16 != 0:
        # Create an image padded to the required size with mode 'RGBA'
        pad = Image.new('RGBA', (Screen_Size_X, Screen_Size_Y)) # Paste the original image into the padded one, set at raspberry camera resolution and rounded for 32 bits(x) and 16 bit (y)
        pad.paste(img, (0, 0))
        print("PAD : ", fname, " Size ", pad.size[0], "x", pad.size[1])
        return pad
    else:
        return img

def getImgResizeScreenResolution (fname):
    """ Charge une image dans un buffer compatible avec la caméra Raspberry pour surimpression
        Le buffer fait Screen_Size_X x Screen_Size_Y, identique à la taille de l'écran
        Si 'image n'est pas 
        Colle l'image initiale en haut à gauche de la zone
        
        Retourne l'image crée
    """
    img = Image.open(fname)
    print("Original Image : ", fname, " Size ", img.size[0], "x", img.size[1])
    img = img.resize((Screen_Size_X, Screen_Size_Y))
    print("Image After Resizing: ", fname, " Size ", img.size[0], "x", img.size[1])
    # Create an image padded to the required size with mode 'RGBA', always create this image as source image may not be RGBA
    pad = Image.new('RGBA', (Screen_Size_X, Screen_Size_Y)) # Paste the original image into the padded one, set at raspberry camera resolution and rounded for 32 bits(x) and 16 bit (y)
    pad.paste(img, (0, 0))
    print("PAD : ", fname, " Size ", pad.size[0], "x", pad.size[1])
    return pad

def PressThrowButton():
    """ Fonction appelée quand le bouton "Jeter" est pressé
        Se contente de positionner la variable globale correspondante
        
        Ne retourne rien
    """
    global ButtonThrowIsPressed
    #print ("Bouton Rouge\n")
    ButtonThrowIsPressed = 1

def PressKeepButton():
    """ Fonction appelée quand le bouton "garder" est pressé
        Se contente de positionner la variable globale correspondante
        
        Ne retourne rien
    """
    global ButtonKeepIsPressed
    #print ("Bouton blanc\n")
    ButtonKeepIsPressed = 1

    
    
class thUpload(Thread):
    """ Classe utilisée pour envoyer les fichiers créés vers Google Drive
        Utilise des threads pour faire plusieurs envois en parallèle
    """
    def __init__(self, fname):
        Thread.__init__(self)
        self.fname = fname          #   Nom du fichier à envoyer
    def run (self):
        global NbUpload             #   Utilise une variable globale pour compter le nombre de transferts en cours.
        try:
            NbUpload += 1
            ledDrive.on()           #   Allume la LED, au moins un tarnsfert en cours
            uploadToDrive ( self.fname )
            NbUpload -= 1
            if NbUpload <= 0:
                NbUpload = 0        #   Empeche de devenir négatif (erreur) !
                print("Fin transfert vers Google drive")
                ledDrive.off()      #   Eteint la Led Drive
        except:
            print ("cannot upload picture %s to drive. (%s)" % (self.fname, sys.exc_info()[0]) , file=sys.stderr)
            NbUpload -= 1
            if NbUpload <= 0:
                NbUpload = 0        #   Empeche de devenir négatif (erreur) !
                ledDrive.off()      #   Eteint la Led Drive


# First use working directory
os.chdir(WorkingDir) 
#   Charge les images qui vont être utilisées en overlay
#   La taille des imlages est celle de l'écran
ImageAccueil = getImgScreenResolution ("Accueil.png")
FondEcran = getImgScreenResolution ("Fond.png")
SecondePhoto = getImgScreenResolution("SecondePhoto.png");
DernierePhoto = getImgScreenResolution("DernierePhoto.png");
apresPhoto = getImgScreenResolution ("ApresPhoto2.png")
waits = []
for i in range(3):
    waits.append(getImgScreenResolution ("%d.png" % (i+1)))

#   Initialise l'image composite
#   Crée une image de la taille finale et colle la 4ème (fixe) en bas à droite
print("Taille image Quatre = (", QuadPhoto_Size_X, ",", QuadPhoto_Size_Y, ")")
print("Position images, 0=(", QuadPhoto_Img0_X, ",", QuadPhoto_Img0_Y, ")  1=(",  QuadPhoto_Img1_X, ",", QuadPhoto_Img1_Y, ")  2=(",  QuadPhoto_Img2_X, ",", QuadPhoto_Img2_Y, ")") 
QuadImage = Image.new("RGB",(QuadPhoto_Size_X, QuadPhoto_Size_Y), (255, 255, 255) )        #Crée l'image composite (init en blanc)
ImageQuatre = Image.open(ImageFond)
QuadImage.paste(ImageQuatre, ( 0, 0) )                # Copie l'image
#   Initialise la partie son, basée sur pygames
pygame.mixer.init()
pygame.mixer.music.set_volume(1.0)

# add an overlay which cut the picture at the right size (camera format is 4/3)
o1 = camera.add_overlay(FondEcran.tobytes(), size=(Screen_Size_X,Screen_Size_Y), format='rgba', layer=1, vflip=camera.vflip, hflip=camera.vflip)
camera_preview = camera.start_preview(resolution=(Screen_Size_Preview_X, Screen_Size_Preview_Y))    #start preview with format 4/3
camera_preview.fullscreen = True
while True:
    try:
        buttonKeep.when_pressed = None
        buttonThrow.when_pressed = None

        # Affiche les instructions (appyer sur gros bouton vert) au dessus de l'image de la camera
        # Reduit l'image de la camera au dimensions de l'affichage et non à sa résolution réelle.
        # Utilise un overlay 32 bits (RGBA) pour profiter du paramètre transparence des fichiers PNG
        # Cela économise beaucoup de calculs sur le raspberry
        # Les paramètres de Flip (H et V) sont positionnés ici. PAr défaut HFlip = True et VFlip = False
        # Le niveau d'overlay doit être plus grand que 2 qui est le niveau par défaut de la caméra en mode preview
        o3 = camera.add_overlay(ImageAccueil.tobytes(), size=(Screen_Size_X,Screen_Size_Y), format='rgba', layer=3, vflip=camera.vflip, hflip=camera.vflip)

        # Fait clignoter le bouton vert pour inciter à appuyer dessus
        ledPhoto.pulse(2,2)
        buttonPhoto.wait_for_press()
        # Si le code ici est atteint, le bouton a été pressé.
        # Passe en phase prise de photo
        # Clignotement différent bouton
        ledPhoto.pulse (fade_in_time=0.125, fade_out_time=0.125, n=16, background=True)
        # Enlève l'image overlay donnat les instructions
        camera.remove_overlay(o3)
        
        # Première photo
        # Charge le son qui va être joué
        indexSound = random.randrange(7)
        pygame.mixer.music.load(SoundFiles[indexSound])
        # Affiche 3 .. 2 .. 1 avant de prendre la photo en Overlay au dessus de l'image
        for i in range(2, -1, -1):
            o3 = camera.add_overlay(waits[i].tobytes(),  size=(Screen_Size_X,Screen_Size_Y), format='rgba', layer=3, vflip=camera.vflip, hflip=camera.vflip)
            if i == 0:
                # Au dernier pas, joue le son qui dure environ 1s, cohérent avec l'attente
                pygame.mixer.music.play()
                while pygame.mixer.music.get_busy() == True:
                    continue
            else:
                #sinon attent 1s avant de changer d'image
                sleep(1)
            camera.remove_overlay(o3)
        # capture still image from camera
        outfile1 = PhotoDir + '/MP-1-%s.jpg' % ( strftime("%Y%m%d-%H%M%S", localtime() ) )
        camera.capture( outfile1 )

        # Seconde photo

        o3 = camera.add_overlay(SecondePhoto.tobytes(),  size=(Screen_Size_X,Screen_Size_Y), format='rgba', layer=3, vflip=camera.vflip, hflip=camera.vflip)
        #Ajoute l'image 1 capturée, fait cela maintenant avec le texte affiché
        Image1 = Image.open(outfile1)
        QuadImage.paste(Image1, (QuadPhoto_Img0_X, QuadPhoto_Img0_Y))
        # upload pictures to google drive if enabled
        if UploadGoogleDrive > 0:
            th = thUpload (outfile1)
            th.start()
        del Image1
        sleep(1)        #Attente le temps de lire le texte...
        camera.remove_overlay(o3)
        # Charge le son qui va être joué
        indexSound = random.randrange(7)
        pygame.mixer.music.load(SoundFiles[indexSound])
        # Affiche 2 .. 1 avant de prendre la photo en Overlay au dessus de l'image
        for i in range(1, -1, -1):
            o3 = camera.add_overlay(waits[i].tobytes(),  size=(Screen_Size_X,Screen_Size_Y), format='rgba', layer=3, vflip=camera.vflip, hflip=camera.vflip)
            if i == 0:
                # Au dernier pas, joue le son qui dure environ 1s, cohérent avec l'attente
                pygame.mixer.music.play()
                while pygame.mixer.music.get_busy() == True:
                    continue
            else:
                #sinon attent 1s avant de changer d'image
                sleep(1)
            camera.remove_overlay(o3)
        # capture still image from camera
        outfile2 = PhotoDir + '/MP-2-%s.jpg' % ( strftime("%Y%m%d-%H%M%S", localtime() ) )
        camera.capture( outfile2 )

        # Troisième et dernière photo

        o3 = camera.add_overlay(DernierePhoto.tobytes(),  size=(Screen_Size_X,Screen_Size_Y), format='rgba', layer=3, vflip=camera.vflip, hflip=camera.vflip)
        #Ajoute l'image 3 capturée, fait cela maintenant avec le texte affiché
        Image2 = Image.open(outfile2)
        QuadImage.paste(Image2, (QuadPhoto_Img1_X, QuadPhoto_Img1_Y))
        # upload pictures to google drive
        if UploadGoogleDrive > 0:
            th = thUpload (outfile2)
            th.start()
        del Image2
        sleep(1)
        camera.remove_overlay(o3)
        # Charge le son qui va être joué
        indexSound = random.randrange(7)
        pygame.mixer.music.load(SoundFiles[indexSound])
        # Affiche 2 .. 1 avant de prendre la photo en Overlay au dessus de l'image
        for i in range(1, -1, -1):
            o3 = camera.add_overlay(waits[i].tobytes(),  size=(Screen_Size_X,Screen_Size_Y), format='rgba', layer=3, vflip=camera.vflip, hflip=camera.vflip)
            if i == 0:
                # Au dernier pas, joue le son qui dure environ 1s, cohérent avec l'attente
                pygame.mixer.music.play()
                while pygame.mixer.music.get_busy() == True:
                    continue
            else:
                #sinon attent 1s avant de changer d'image
                sleep(1)
            camera.remove_overlay(o3)
        # capture still image from camera
        outfile3 = PhotoDir+'/MP-3-%s.jpg' % ( strftime("%Y%m%d-%H%M%S", localtime() ) )
        camera.capture( outfile3 )

         #Ajoute l'image 3 capturée
        Image3 = Image.open(outfile3)
        QuadImage.paste(Image3, (QuadPhoto_Img2_X, QuadPhoto_Img2_Y))
        # upload pictures to google drive
        if UploadGoogleDrive > 0:
            th = thUpload (outfile3)
            th.start()
        del Image3

        outfile4 =  PhotoDir + '/MP-4-%s.jpg' % ( strftime("%Y%m%d-%H%M%S", localtime() ) )
        QuadImage.save(outfile4, 'jpeg', quality=85)

        #  Phase suivante : on garde ou on jette ?
        ledPhoto.value = 0
        KeepPicture = 1		#Par defaut on garde
        buttonKeep.when_pressed = PressKeepButton
        buttonThrow.when_pressed = PressThrowButton
        ButtonThrowIsPressed = 0
        ButtonKeepIsPressed = 0

        #Affiche l'image composite
        outover = getImgResizeScreenResolution(outfile4)
        o3 = camera.add_overlay(outover.tobytes(), size=(Screen_Size_X,Screen_Size_Y), format='rgba', layer=3)
        #explain that picture will be displayed and user can choose to keep or throw
        o4 = camera.add_overlay(apresPhoto.tobytes(),  size=(Screen_Size_X,Screen_Size_Y), format='rgba', layer=4, vflip=camera.vflip, hflip=camera.vflip)
        # wait for 10s for user pressing either Keep or Throw.
        # if timeout, the picture will be kept.
        StartTimeAfter = time()
        print("attente choix utilisateur time =", StartTimeAfter)
        while time() - StartTimeAfter < 10:
            if ButtonThrowIsPressed > 0:
                StartTimeAfter -= 10
                KeepPicture = 0
                print("on jette")
            if ButtonKeepIsPressed > 0:
                StartTimeAfter -= 10
                print("on garde")
        print("Choix utilisateur : ", KeepPicture, " at", time())
        buttonKeep.when_pressed = None
        buttonThrow.when_pressed = None
        if KeepPicture > 0:
            # upload pictures to google drive
            if UploadGoogleDrive > 0:
                th = thUpload (outfile4)
                th.start()
            #   Et on imprime...
            if NbPrintCopy > 0:
                print("Impression ", outfile4)
                #Commande a executer lp -d EPSON_XP_860_WIFI -n 2 -o landscape -o fit-to-page FileName
                subprocess.Popen(['/usr/bin/lp', '-d', PrinterName, '-n', str(NbPrintCopy), '-o', 'landscape', '-o', 'fit-to-page', outfile4])
        else:
            os.remove(outfile4)
            print("Remove file")
        camera.remove_overlay(o4)
        camera.remove_overlay(o3)
        camera.annotate_text = ''
    except KeyboardInterrupt:
        camera.remove_overlay(o1)
        camera.stop_preview()
        camera.close()
        break

camera.stop_preview()
camrera.close()

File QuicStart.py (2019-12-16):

"""
Shows basic usage of the Drive v3 API.

Creates a Drive v3 API service and prints the names and ids of the last 10 files
the user has access to.
"""
from __future__ import print_function
from apiclient.discovery import build
from httplib2 import Http
from oauth2client import file as oauth_file, client, tools

# Setup the Drive v3 API
SCOPES = 'https://www.googleapis.com/auth/drive.file'
store = oauth_file.Storage('CamilleYann_Token.json')
creds = store.get()
if not creds or creds.invalid:
    flow = client.flow_from_clientsecrets('MariageCamilleYann-6a097385bb95.json', SCOPES)
    creds = tools.run_flow(flow, store)
service = build('drive', 'v3', http=creds.authorize(Http()))

# Call the Drive v3 API
results = service.files().list(
    pageSize=10, fields="nextPageToken, files(id, name)").execute()
items = results.get('files', [])
if not items:
    print('No files found.')
else:
    print('Files:')
    for item in items:
        print('{0} ({1})'.format(item['name'], item['id']))
